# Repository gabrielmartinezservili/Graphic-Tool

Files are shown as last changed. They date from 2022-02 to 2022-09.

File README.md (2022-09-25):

# Open Graphic Tool

**FR&#8201;:** Cet objet est un outil graphique manifeste conçu pour être fabriqué par impression 3D.  Il s'agit d'une tentative de revalorisation de nos interactions avec le monde des objets techniques. Dans l'objectif de susciter un engagement entre l'individu, l'outil et son fonctionnement. Il a été conçu pour que chacun puisse se l'approprier. Il est modulaire et ouvert, sa conception est totalement transparente.

**EN&#8201;:** *This object is a manifest graphic tool designed to be manufactured using 3D printing.  It is an attempt to revalue our interactions with the world of technical objects. With the aim of bringing about an engagement between the individual, the tool and its functioning. It has been designed so that anyone can make it their own. It is modular and open, its design is totally transparent.*

P1070599

## Why i make it ? </br>

**FR&#8201;:** Lors de mon cursus en école d’Art, j’ai été interpellé par le fait que nous utilisions des objets de production graphique, comme les stylos ou les systèmes d’impression, sans réelle conscience de leur fonctionnement et des phénomènes physiques qu’ils impliquent. Bien qu’il existe une large palette d’outils graphiques, nous faisons nos choix en fonction d’un effet souhaité qui implique l’usage d’un objet précis. L’exploration des possibles est réduite à la portion congrue, nous attendons simplement qu’ils fonctionnent ainsi que nous l’entendons, au travers d’interactions dépourvues de sens et réduites à leur minimum. À partir d’une pratique empirique, je souhaite stimuler l’auto-apprentissage et une forme de jeu graphique qui mélange intuition et spontanéité. Au travers du jeu avec les pièces qui le constituent et la matière (l’encre) qu’il manipule, cet objet graphique donne l’occasion d’explorer de nouveaux procédés. Sa structure composée de diverses parties nous permet de comprendre l’organisation interne de son fonctionnement, puis offre la possibilité de le moduler avec différentes pointes qui influencent l’écoulement de l’encre et son dépôt sur le support. 

Vous trouverez dans les différents dossiers, **[Les fichiers 3D](https://github.com/gabrielmartinezservili/Graphic-Tool/tree/main/Graphic%20tool/3D%20files%20%28STL%29)** avec des exemples de paramétrage, **[la notice](https://github.com/gabrielmartinezservili/Graphic-Tool/blob/main/Graphic%20tool/Instructions%20and%20Tutorials/Notice_FR.pdf)** et des **[tutoriels vidéo](https://github.com/gabrielmartinezservili/Graphic-Tool/blob/main/Graphic%20tool/Instructions%20and%20Tutorials/Tutorials%20%28Video%29.md)**.

---

**EN&#8201;:** *During my art school studies, I was challenged by the fact that we use graphic production objects, such as pens or printing systems, without any real awareness of their functioning and the physical phenomena they imply. Although there is a wide range of graphic tools available, we make our choices according to a desired effect that implies the use of a specific object. The exploration of the possible is reduced to a minimum, we simply expect them to work as we understand them, through meaningless and minimal interactions. From an empirical practice, I wish to stimulate self-learning and a form of graphic play that mixes intuition and spontaneity. Through the play with the parts that constitute it and the material (ink) that it manipulates, this graphic object gives the opportunity to explore new processes. Its structure, composed of various parts, allows us to understand the internal organisation of its functioning, and then offers the possibility of modulating it with different tips that influence the flow of the ink and its deposit on the support.*

You will find in the different folders, **[the 3D files](https://github.com/gabrielmartinezservili/Graphic-Tool/tree/main/Graphic%20tool/3D%20files%20%28STL%29)** with examples of settings, **[the instructions]([https://github.com/gabrielmartinezservili/Graphic-Tool/blob/main/Graphic%20tool/Instructions%20and%20Tutorials/Notice.pdf](https://github.com/gabrielmartinezservili/Graphic-Tool/blob/main/Graphic%20tool/Instructions%20and%20Tutorials/Notice_EN.pdf))** and **[tutorials videos](https://github.com/gabrielmartinezservili/Graphic-Tool/blob/main/Graphic%20tool/Instructions%20and%20Tutorials/Tutorials%20%28Video%29.md)**.

P1070295

---

# Technicals Informations

I personally use [Prusa Slicer](https://www.prusa3d.com/fr/page/prusaslicer_424/) for slicing. It allows me to vary the patterns and perimeter settings in more detail by adding constraints to the STL file. But I use [CURA](https://ultimaker.com/fr/software/ultimaker-cura) with **printable overhang** option to slice the *Ball point*. The parameters of the 3MF files correspond to those of my printer, adjust them for your machine, otherwise it may damage it or even cause breakdowns.

*See the [PDF leaflet](https://github.com/gabrielmartinezservili/Graphic-Tool/blob/main/Graphic%20tool/Instructions%20and%20Tutorials/Notice_EN.pdf) for more information.*

|Elements |Material | Print settings |
|---|---|---
|Ball tip seal | *TPE *(93A)** |*layer height: 0.2mm or 0.28*
|Ball point |  *PLA* | *layer height: 0.08 ou 0.16mm*
|Ball | *stainless steel* |x
|Support seal | *PLA* |*layer height: 0.2mm*
|Crown | *PLA* |*layer height: 0.08 ou 0.16mm*
|Shutters | *TPE *(93A)** |*layer height: 0.2mm*[^2]
|Cap | *PLA* |*layer height: 0.08 ou 0.16mm*
|Cap seal | *TPE *(93A)** |*layer height: 0.2mm or 0.28*
|Tank | *PLA* |*layer height: 0.08 ou 0.16mm*
|TPE Tank |  *TPE *(93A)** | *layer height: 0.08 ou 0.16mm*
|Tank seal | *TPE *(93A)** |*layer height: 0.2mm or 0.28*
|Thick tip | *TPE *(93A)** |*layer height: 0.2mm*[^2]
|Thin tip | *TPE *(93A)** |*layer height: 0.2mm*[^2]
|Bevelled tip | *TPE *(93A)** |*layer height: 0.2mm*[^3]

P1070351

[^1]: The parameters of the 3MF files correspond to those of my printer, adjust them for your machine, otherwise it may damage it or even cause breakdowns.

[^2]:  Be careful that the first layer does not completely merge the chosen patterns.

[^3]: Don't need special parameters.

My instagram&#8201;: https://www.instagram.com/gabrielmartinez.ser/

<br />This work is licensed under a <a rel="license" href="http://creativecommons.org/licenses/by-nc-sa/4.0/">Creative Commons Attribution-NonCommercial-ShareAlike 4.0 International License</a>.

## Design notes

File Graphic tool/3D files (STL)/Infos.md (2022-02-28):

I personally use [Prusa Slicer](https://www.prusa3d.com/fr/page/prusaslicer_424/) for slicing. It allows me to vary the patterns and perimeter settings in more detail by adding constraints to the STL file[^1]. 

*See the PDF leaflet for more information.*

|Elements |Material | Print settings |
|---|---|---
|  Seal |  *TPE *(93A)** |*layer height: 0.2mm*
|Support seal | *PLA* |*layer height: 0.2mm*
|Crown | *PLA* |*layer height: 0.08 ou 0.16mm*
|Shutter | *TPE *(93A)** |*layer height: 0.2mm*[^2]
|Ball point |  *PLA* | *layer height: 0.08 ou 0.16mm*
|Cap | *PLA* |*layer height: 0.08 ou 0.16mm*
|Tank | *PLA* |*layer height: 0.08 ou 0.16mm*
|Ball | *stainless steel* |x
|Thick tip | *TPE *(93A)** |*layer height: 0.2mm*[^2]
|Thin tip | *TPE *(93A)** |*layer height: 0.2mm*[^2]

[^1]: The parameters of the 3MF files correspond to those of my printer, adjust them for your machine, otherwise it may damage it or even cause breakdowns.

[^2]:  Be careful that the first layer does not completely merge the chosen patterns.

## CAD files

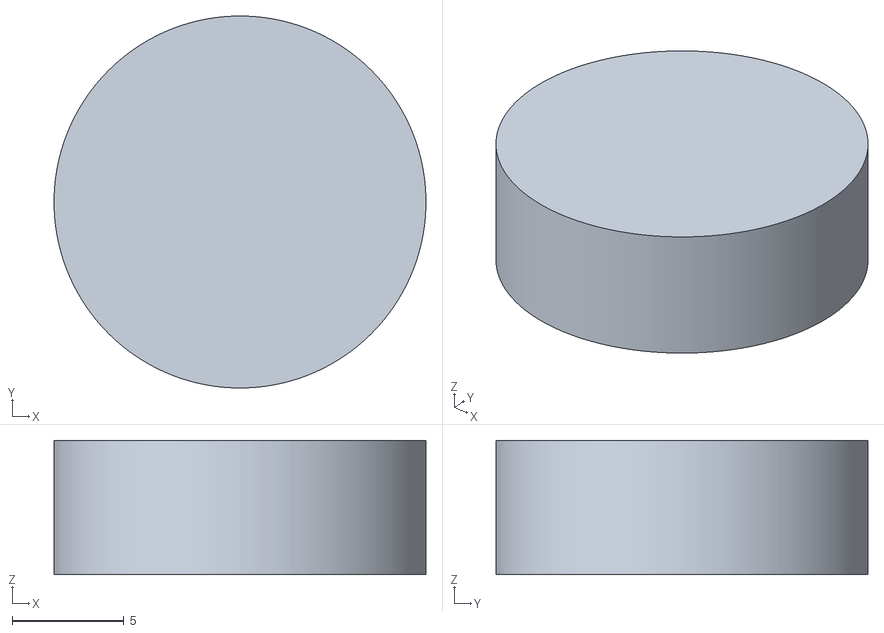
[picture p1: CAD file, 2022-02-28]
Graphic tool/3D files (STL)/Shutters/Shutters.stl
16.6 x 16.6 x 6.00

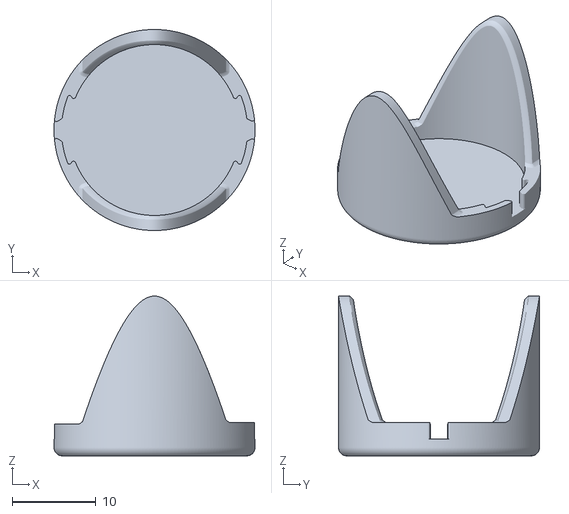
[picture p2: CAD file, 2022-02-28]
Graphic tool/3D files (STL)/Storage boxes/Base_tips_box.stl
24.0 x 24.0 x 19.1

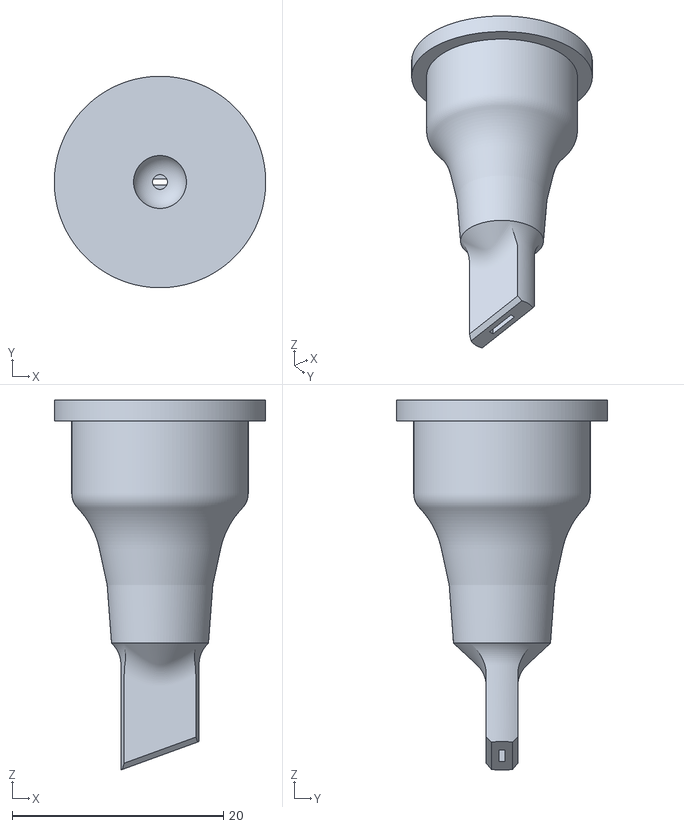
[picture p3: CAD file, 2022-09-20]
Graphic tool/3D files (STL)/Tips/Flexible tips (TPE)/Bevelled_tip.stl
20.0 x 20.0 x 35.0

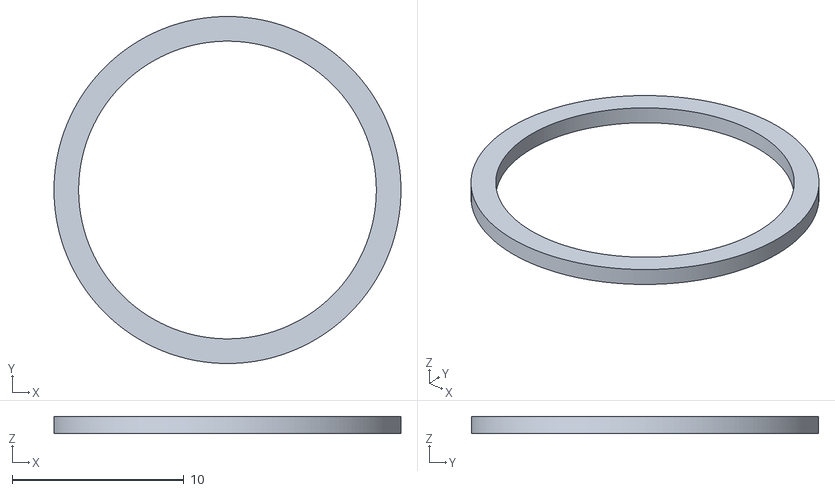
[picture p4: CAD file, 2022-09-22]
Graphic tool/3D files (STL)/TPU seals/cap_seal.stl
20.2 x 20.2 x 1.00

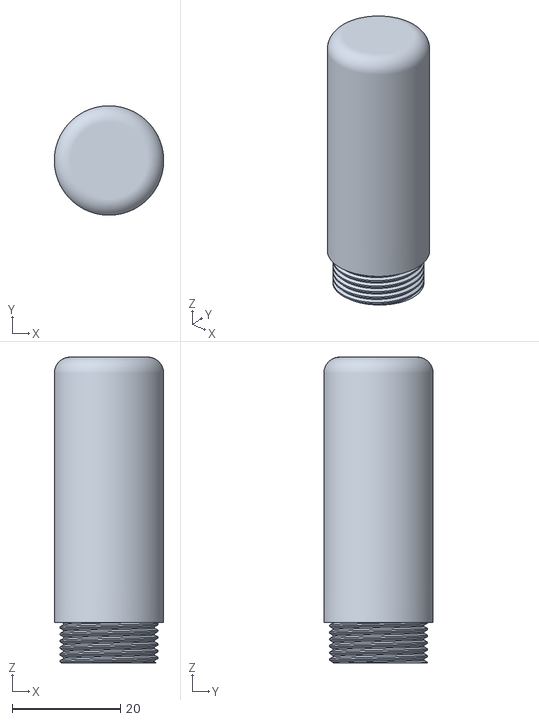
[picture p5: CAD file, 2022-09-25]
Graphic tool/3D files (STL)/tpu_tank.stl
20.2 x 20.2 x 56.5

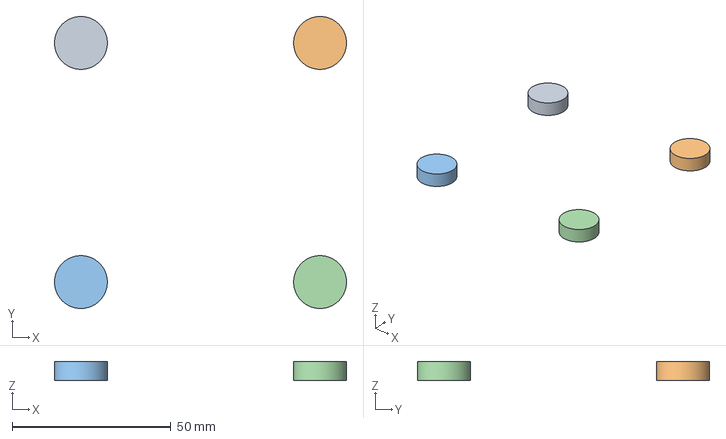
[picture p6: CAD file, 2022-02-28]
Graphic tool/3D files (STL)/Shutters/Examples_shutters_parameters.3mf
91.9 x 91.9 x 6.00 mm
obturateur.stl x 4

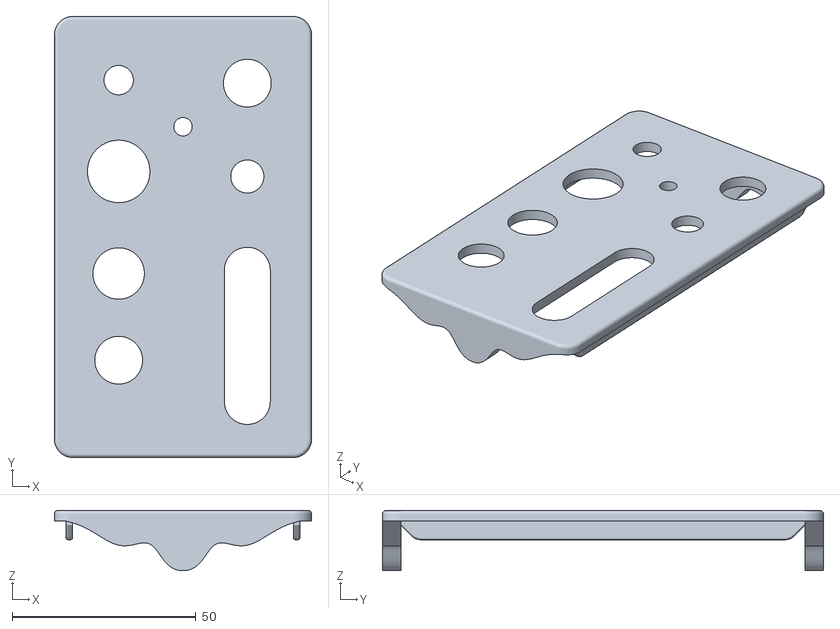
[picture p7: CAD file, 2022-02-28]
Graphic tool/3D files (STL)/Storage boxes/Cover_tool_box.stl
70.0 x 120.0 x 16.4

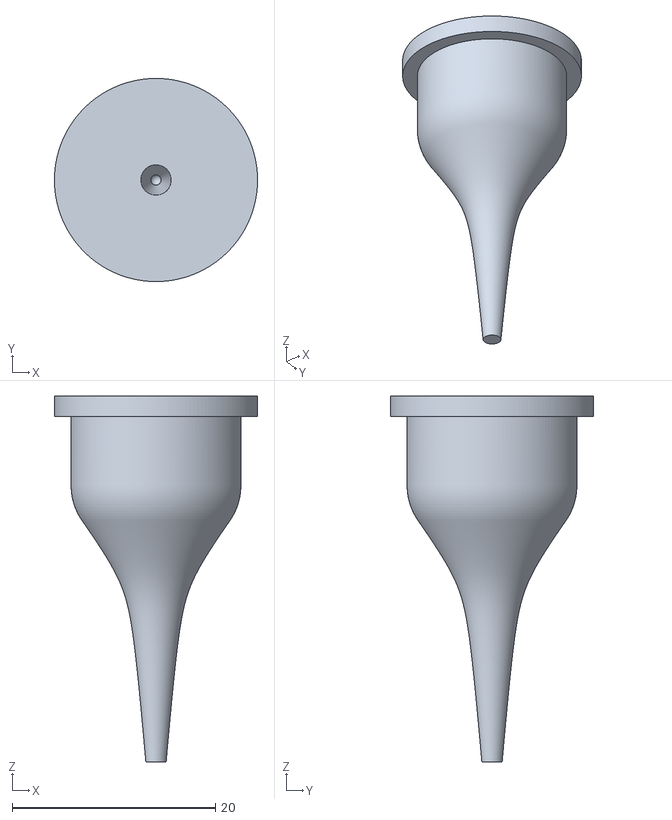
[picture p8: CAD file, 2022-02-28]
Graphic tool/3D files (STL)/Tips/Flexible tips (TPE)/Thin_tip.stl
20.0 x 20.0 x 36.0

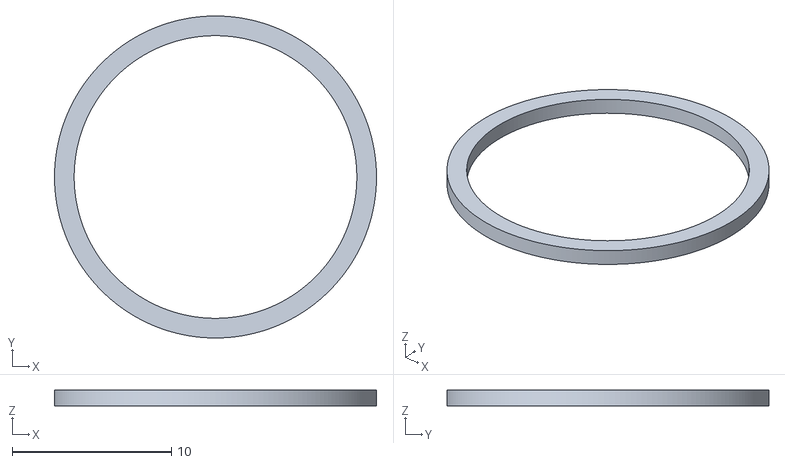
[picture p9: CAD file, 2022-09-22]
Graphic tool/3D files (STL)/TPU seals/tank_seal.stl
20.2 x 20.2 x 1.00

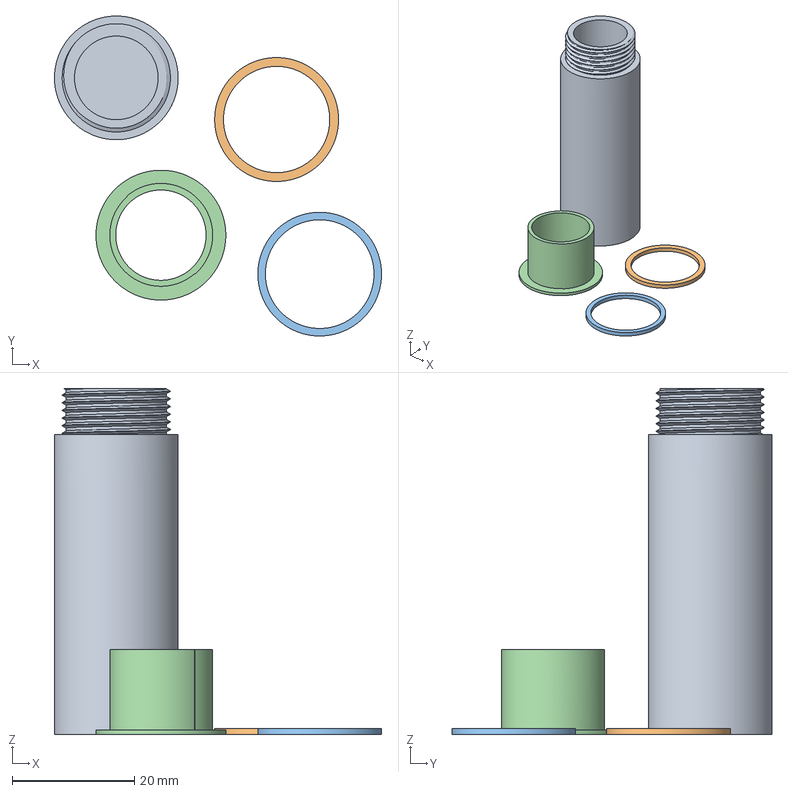
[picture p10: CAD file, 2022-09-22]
Graphic tool/3D files (STL)/tpu_seal_tank.3mf
53.4 x 52.2 x 56.5 mm
Reservoir_tpu.stl
joint_capuchon.stl
joint_tubeR.stl
ball_tip_seal.stl

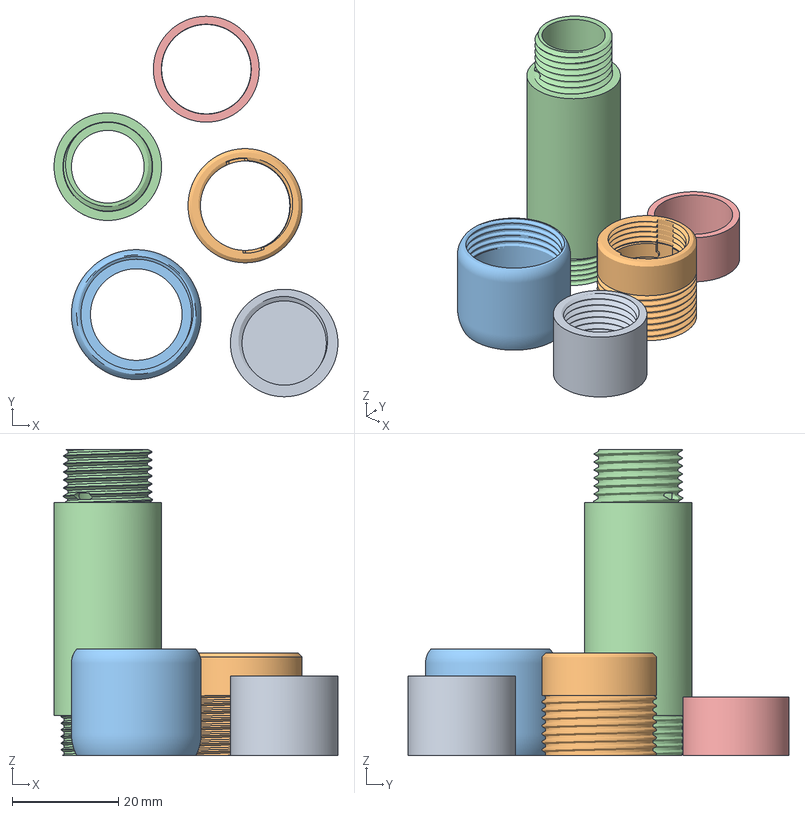
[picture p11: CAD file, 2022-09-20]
Graphic tool/3D files (STL)/kit_ender_3.3mf
53.3 x 71.5 x 57.5 mm
cap.stl
connector.stl
crown.stl
tank.stl
seal_support.stl

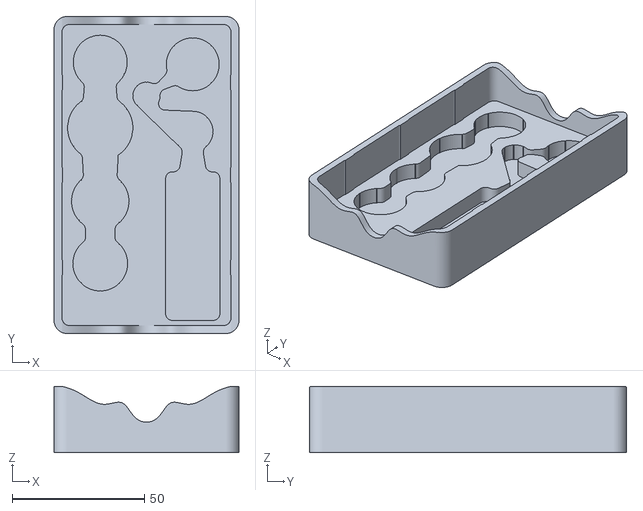
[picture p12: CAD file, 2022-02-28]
Graphic tool/3D files (STL)/Storage boxes/Base_tool_box.stl
70.0 x 120.0 x 25.0

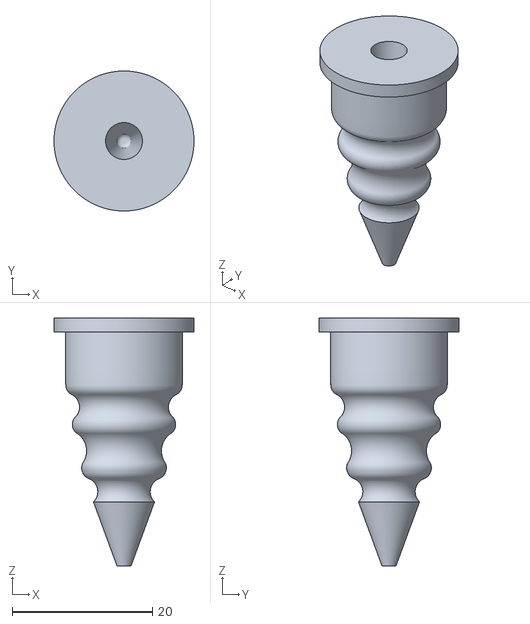
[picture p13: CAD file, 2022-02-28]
Graphic tool/3D files (STL)/Tips/Flexible tips (TPE)/Thick_tip.stl
20.0 x 20.0 x 35.4

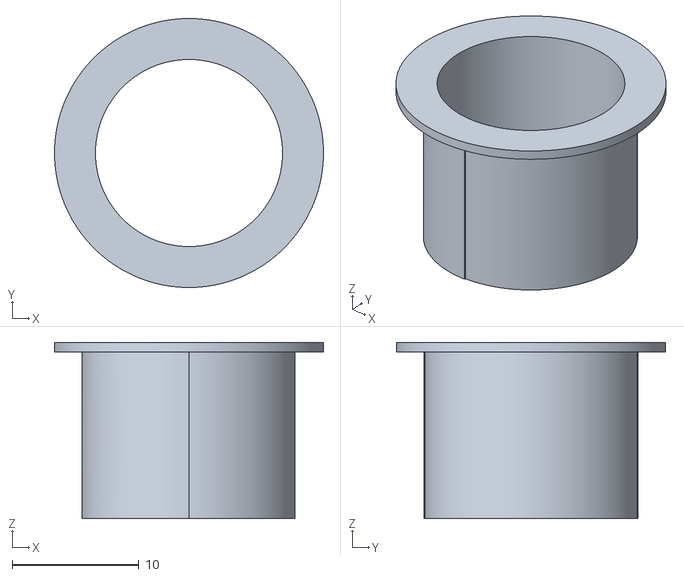
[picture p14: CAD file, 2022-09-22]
Graphic tool/3D files (STL)/TPU seals/ball_tip_seal.stl
21.2 x 21.2 x 13.9

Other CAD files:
Graphic tool/3D files (STL)/crown.stl
Graphic tool/3D files (STL)/Storage boxes/Cover_tips_box.stl
Graphic tool/3D files (STL)/Tips/Flexible tips (TPE)/example_parameter_flexible_tip.3mf
Graphic tool/3D files (STL)/connector.stl
Graphic tool/3D files (STL)/Storage boxes/Base_shutters_box.stl
Graphic tool/3D files (STL)/Storage boxes/Cover_shutters_box.stl
Graphic tool/3D files (STL)/cap.stl
Graphic tool/3D files (STL)/cura_ball_point.3mf
Graphic tool/3D files (STL)/seal_support.stl
Graphic tool/3D files (STL)/tank.stl

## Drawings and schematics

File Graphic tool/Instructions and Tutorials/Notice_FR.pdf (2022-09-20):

# Notice

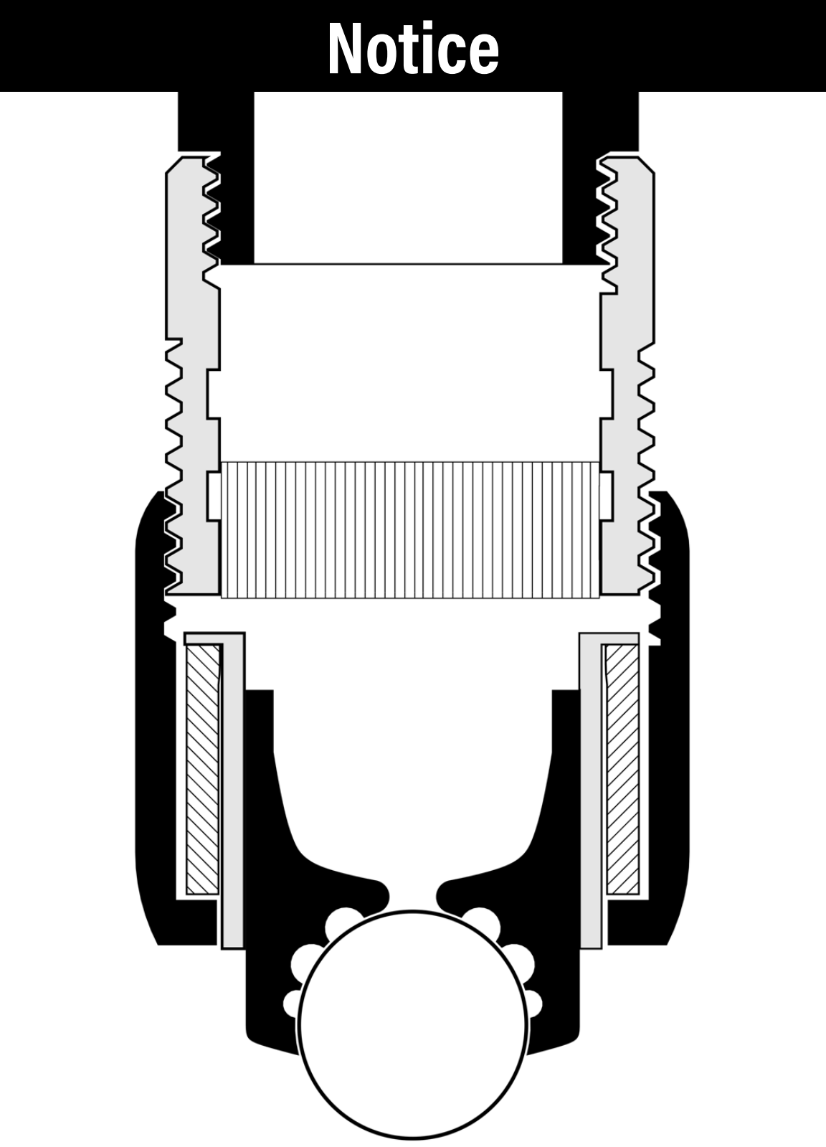
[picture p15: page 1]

1 | 6
2 | B

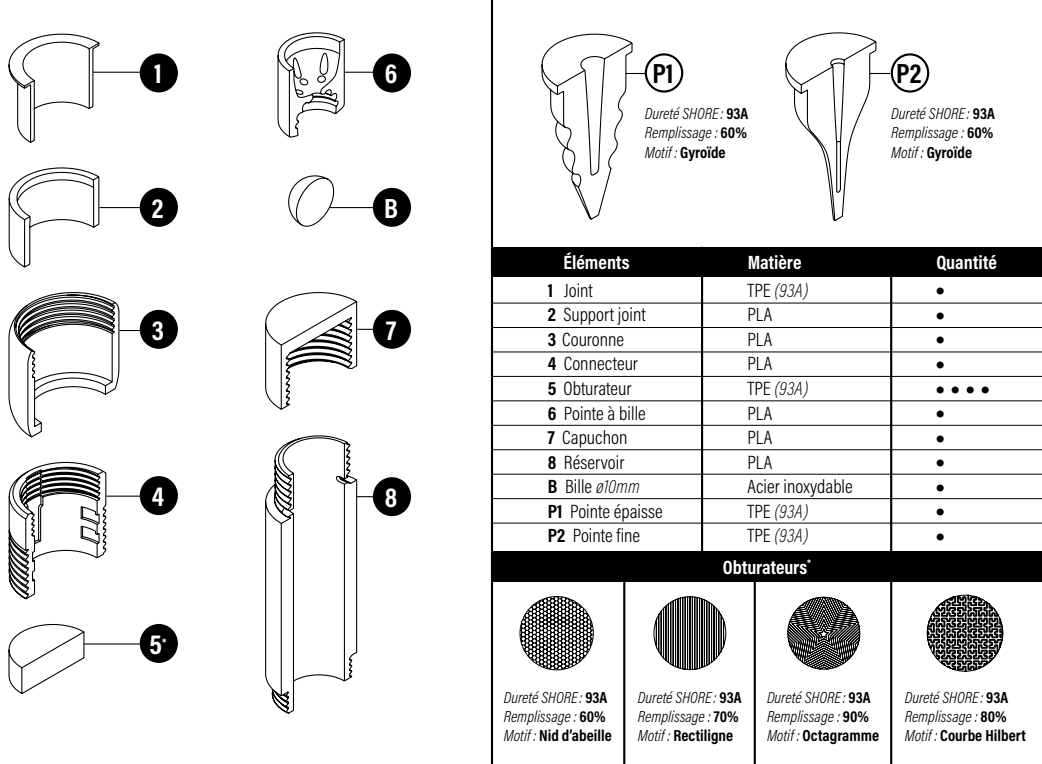
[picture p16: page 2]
1 Joint 2 Support joint 3 Couronne 4 Connecteur 5 Obturateur 6 Pointe à bille 7 Capuchon 8 Réservoir B Bille ø10mm P1 Pointe épaisse P2 Pointe fine; TPE (93A) PLA PLA PLA TPE (93A) PLA PLA PLA Acier inoxydable TPE (93A) TPE (93A); Éléments; Matière; Quantité; Dureté SHORE: 93A Remplissage : 60% Motif : Gyroïde; Dureté SHORE: 93A Remplissage : 90% Motif : Octagramme; Dureté SHORE: 93A Remplissage : 70% Motif : Rectiligne; Obturateurs*

Dureté SHORE: 93A
Remplissage : 60%
Motif : Nid d’abeille

Remplissage : 80%
Motif : Courbe Hilbert

1

P1

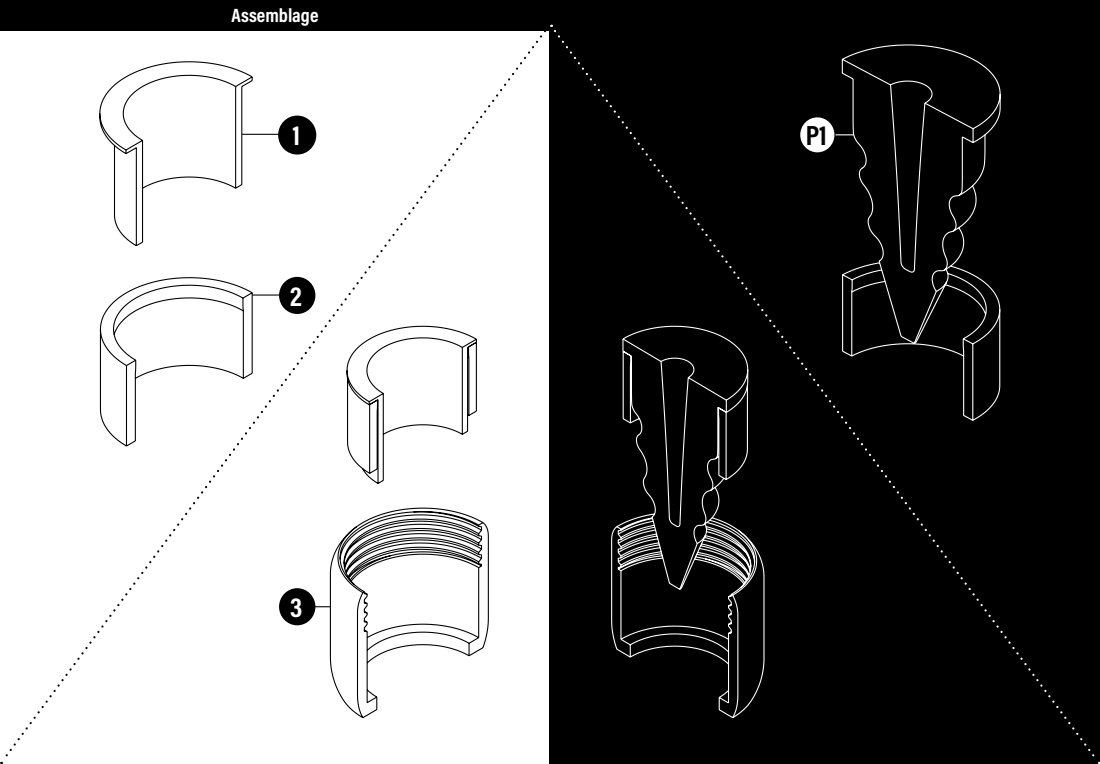
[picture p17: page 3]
Assemblage

4

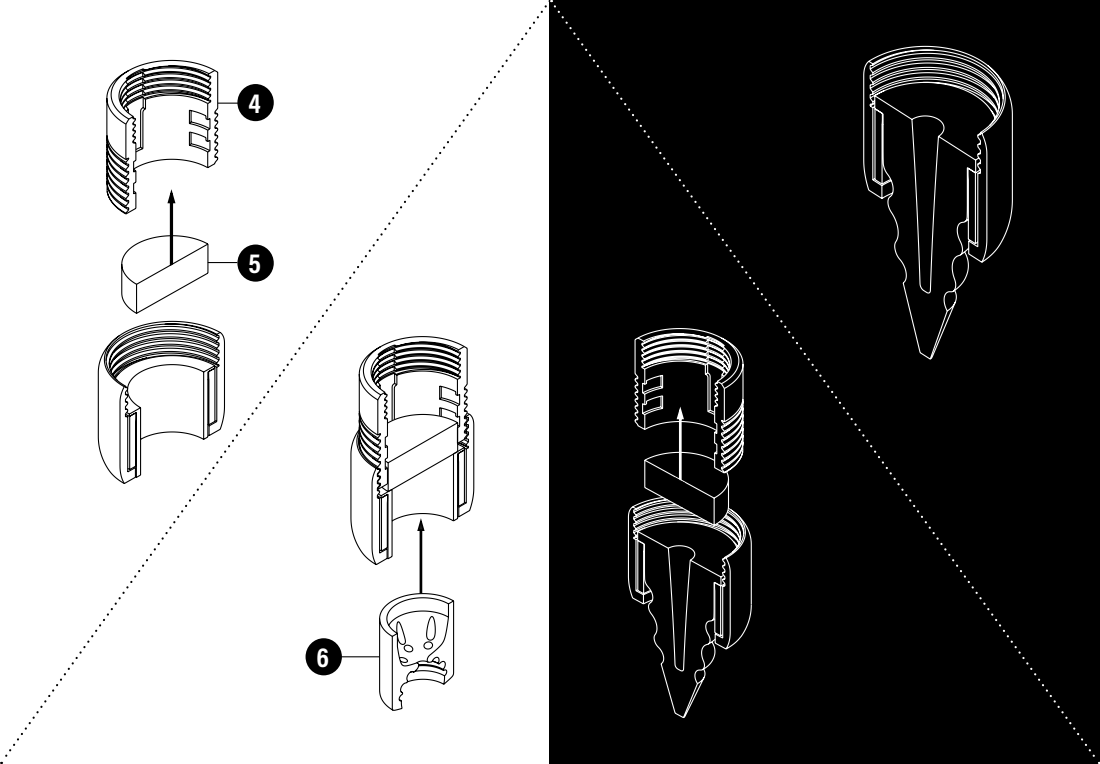
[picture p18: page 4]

78

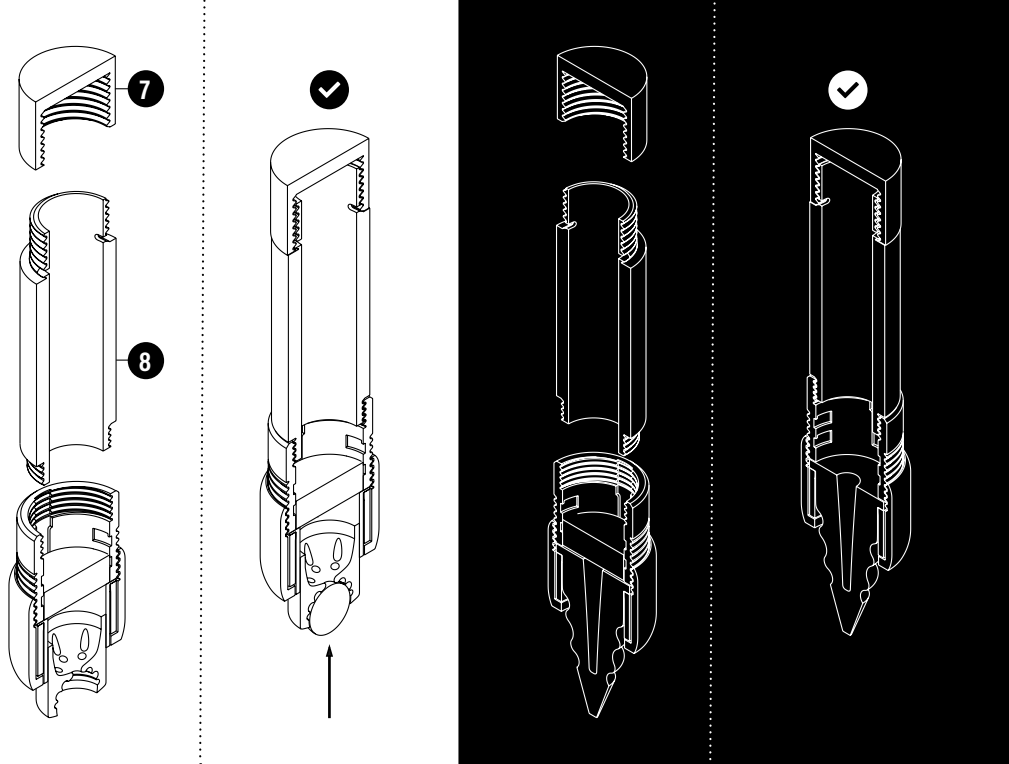
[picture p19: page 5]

Remplissage de l’encre

Notes

Écoulement / Débit

Encres

Les obturateurs permettent d’ajuster le débit et l’arrivée de matière en fonction de l’encre utilisée.
Pour permettre à l’encre de s’écouler il suffit de dévisser plus ou moins le capuchon. Attention il est très sensible.

Accepte tout type d’encres, peut être utilisé avec de la peinture, ou toute forme de matière qui peut s’écouler.

Si l’objet est imprimé en PLA, faire attention à la température de nettoyage, au dessus de 60°C ce matériau se déforme.
À stocker à l’abris du soleil, les UV dégradent le PLA, le rendant plus cassant et friable.
Graisser les filetages est une solution pour minimiser les fuites, utiliser de la graisse synthétique de préférences.
Certains solvants attaquent le PLA et les plastiques en général.

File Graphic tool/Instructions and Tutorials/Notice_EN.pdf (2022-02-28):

# Notice


1 | 6
2 | B

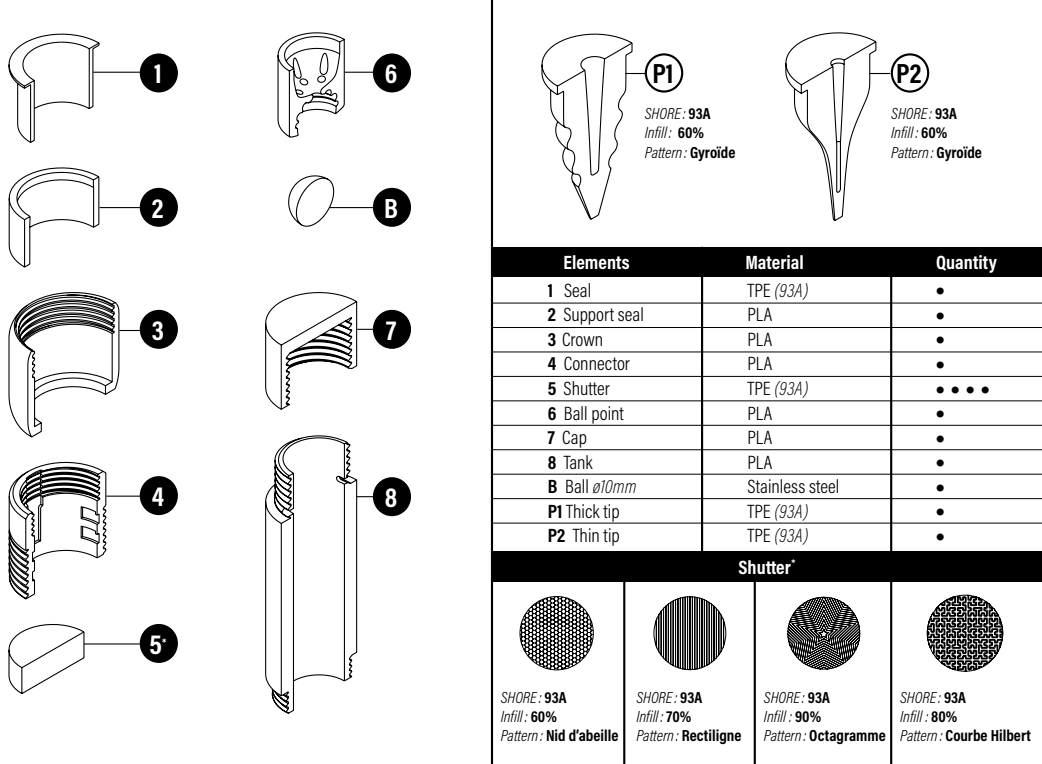
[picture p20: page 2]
1 Seal 2 Support seal 3 Crown 4 Connector 5 Shutter 6 Ball point 7 Cap 8 Tank B Ball ø10mm P1 Thick tip P2 Thin tip; TPE (93A) PLA PLA PLA TPE (93A) PLA PLA PLA Stainless steel TPE (93A) TPE (93A); Elements; Material; Quantity; SHORE : 93A Infill : 60% Pattern : Gyroïde; SHORE : 93A Infill : 90% Pattern : Octagramme; SHORE : 93A Infill : 70% Pattern : Rectiligne; Shutter*

SHORE : 93A
Infill : 60%
Pattern : Nid d’abeille

Infill : 80%
Pattern : Courbe Hilbert

1

P1

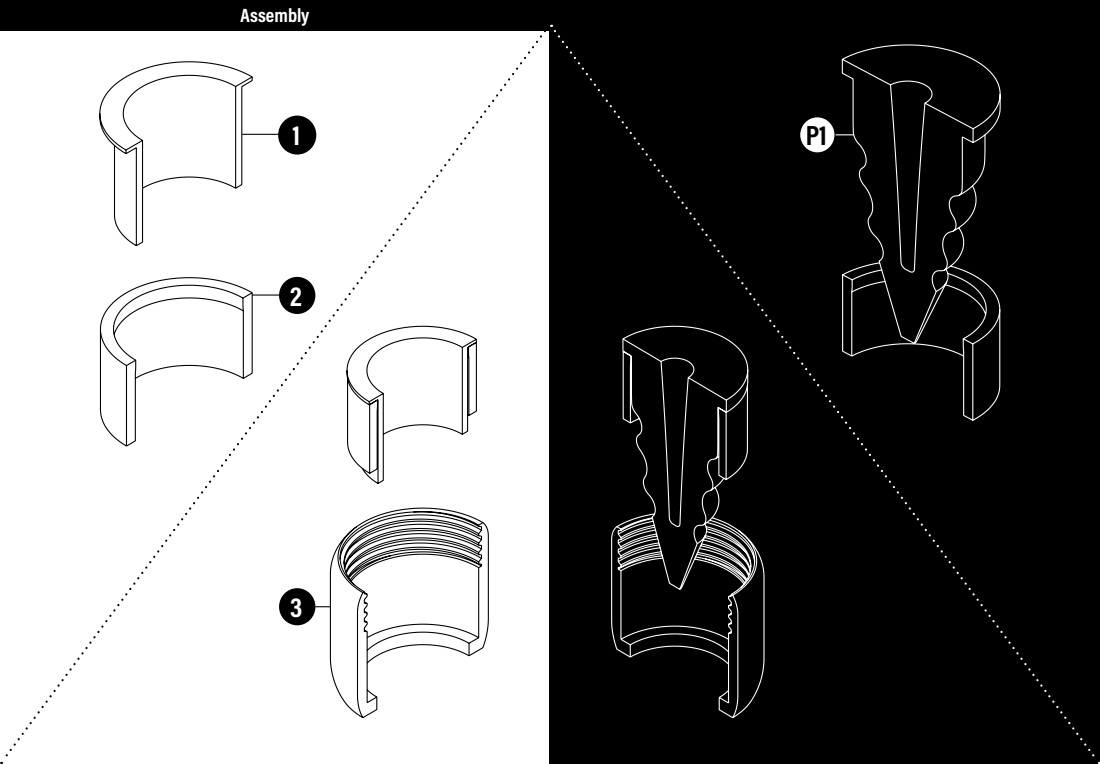
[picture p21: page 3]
Assembly

4


78


Ink filling

Notes

Flow / Flow rate

Inks

The shutters allow the flow rate and material flow to be adjusted according to the ink used.
To allow the ink to flow, simply unscrew the cap more or less. Be careful, it’s very sensitive.

Accepts all types of inks, can be used with paint, or any form of material that can flow.

If the object is printed in PLA, pay attention to the cleaning tempe-rature, above 60°C this material deforms.
Store away from the sun, as UV rays degrade PLA, making it more brittle and crumbly.
Greasing the threads is one solution to minimise leakage, preferably using synthetic grease.
Some solvents attack PLA and plastics in general.

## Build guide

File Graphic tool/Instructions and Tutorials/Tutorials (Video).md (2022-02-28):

## Assembly

https://user-images.githubusercontent.com/71280824/156076457-be27e7bb-7e41-4566-afa7-8967b942eb45.mp4

# Activation

https://user-images.githubusercontent.com/71280824/156076514-beeab085-ed29-45fd-aa8a-286cfeb5eeb1.mp4
